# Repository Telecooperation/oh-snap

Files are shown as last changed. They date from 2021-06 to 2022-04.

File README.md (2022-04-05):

<p align="center">
  Oh, Snap!
</p>

<h1 align="center">Oh, Snap!</h1>
<p align="center">A Fabrication Pipeline to Magnetically Connect Conventional and 3D-Printed Electronics.</p>

<div align="center">
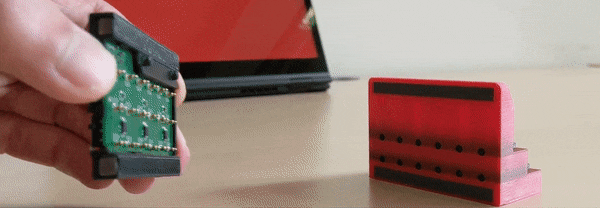
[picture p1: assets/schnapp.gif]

  <br />
    <!--<a href="https://github.com/othneildrew/Best-README-Template"><strong>Explore the docs »</strong></a>
    <br />
    <br />-->
  <h4 align="center">
    <a href="https://www.youtube.com/watch?v=JX3ZwKnnJVs">Watch Teaser</a>
    ·
    <a href="/assets/Schmitz2021-OhSnap.pdf">View PDF</a>
    ·
    <a href="https://www.youtube.com/watch?v=0AUrrtwaPVQ">Watch Talk</a>
    ·
    <a href="https://doi.org/10.1145/3411764.3445641">Follow DOI</a>
    </h4>
</div>

## Paper Abstract
3D printing has revolutionized rapid prototyping by speeding up the creation of custom-shaped objects. With the rise of multi-material 3D printers, these custom-shaped objects can now be made interactive in a single pass through passive conductive structures. However, connecting conventional electronics to these conductive structures often still requires time-consuming manual assembly involving many wires, soldering or gluing.

To alleviate these shortcomings, we propose <i>Oh, Snap!</i>: a fabrication pipeline and interfacing concept to magnetically connect a 3D-printed object equipped with passive sensing structures to conventional sensing electronics. To this end, <i>Oh, Snap!</i> utilizes ferromagnetic and conductive 3D-printed structures, printable in a single pass on standard printers. We further present a proof-of-concept capacitive sensing board that enables easy and robust magnetic assembly to quickly create interactive 3D-printed objects. We evaluate <i>Oh, Snap!</i> by assessing the robustness and quality of the connection and demonstrate its broad applicability by a series of example applications.

## How to use
We provide the schematics and firmware for the Oh, Snap board for capacitive sensing, as well as sample code and 3D models used for the example applications in the paper.

### Schematics
The [schematics](/schematics/) folder contains all schematics to clone the presented Oh, Snap board or use them as a basis for another kind of board. The schematics are provided in Eagle format.

### Firmware
The [firmware](/firmware/) folder contains the firmware required to operate the Oh, Snap board. Please see [firmware/README.md](/firmware/README.md) for more details on the flashing procedure.

### Example Applications
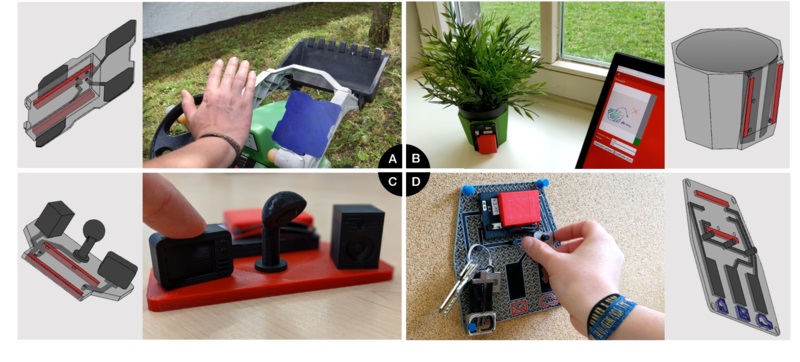
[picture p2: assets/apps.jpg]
Apps


The [examples](/examples/) folder contains code for some example applications:
- [Car Gesture](examples/gesture) (A)
- [Flowerpot](examples/flowerpot) (B)
- [Smarthome Control](examples/smarthome) (C)
- [Piano](examples/piano)

In addition, it also contains some simple monitoring demos.

### 3D Models
For the 3D models used for the example applications and the evaluation see [here](models/).

## How to cite
Please cite this work like this:
<pre>
  Martin Schmitz, Jan Riemann, Florian Müller, Steffen Kreis, and Max Mühlhäuser. 2021. 
  Oh, Snap! A Fabrication Pipeline to Magnetically Connect Conventional and 3D-Printed Electronics. 
  In Proceedings of the 2021 CHI Conference on Human Factors in Computing Systems (CHI ’21), 1–11. 
  https://doi.org/10.1145/3411764.3445641
  </pre>

or use this

<pre>
@inproceedings{10.1145/3411764.3445641,
author = {Schmitz, Martin and Riemann, Jan and M\"{u}ller, Florian and Kreis, Steffen and M\"{u}hlh\"{a}user, Max},
title = {Oh, Snap! A Fabrication Pipeline to Magnetically Connect Conventional and 3D-Printed Electronics},
year = {2021},
isbn = {9781450380966},
publisher = {Association for Computing Machinery},
address = {New York, NY, USA},
url = {https://doi.org/10.1145/3411764.3445641},
doi = {10.1145/3411764.3445641},
booktitle = {Proceedings of the 2021 CHI Conference on Human Factors in Computing Systems},
articleno = {420},
numpages = {11},
keywords = {capacitive sensing, proximity, touch, prototyping, 3D printing},
location = {Yokohama, Japan},
series = {CHI '21}
}
</pre>

## Credits
This project uses the following sources:
- [Protocentral FDC1004](https://github.com/Protocentral/ProtoCentral_fdc1004_breakout)
- [ESPAsyncWebServer](https://github.com/me-no-dev/ESPAsyncWebServer)
- [MQTT PubSubClient](https://github.com/knolleary/pubsubclient)
- [ArduinoJSON]( https://github.com/bblanchon/ArduinoJson)
- [FreeRTOS]( https://github.com/FreeRTOS/FreeRTOS)
- [Tone.js]( https://github.com/Tonejs/Tone.js)
- [Plotly.js](https://github.com/plotly/plotly.js)
- [Arduino-ESP32](https://github.com/espressif/arduino-esp32)
- [Logo](https://www.pngaaa.com/detail/1826967)

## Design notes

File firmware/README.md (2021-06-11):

# Firmware

## Compile & Flash
- Install VSCode and PlatformIO
- Build the firmware and upload it to the (USB connected) devices

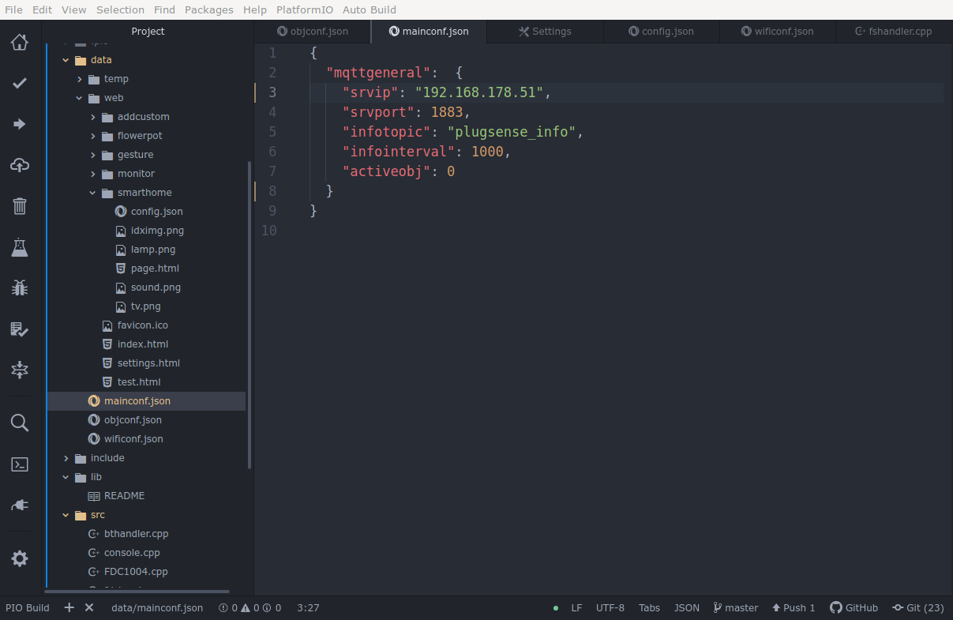
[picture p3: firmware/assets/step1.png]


##  Flash DATA section

- PIO Build (or similar)
- „PIO Upload File System Image“

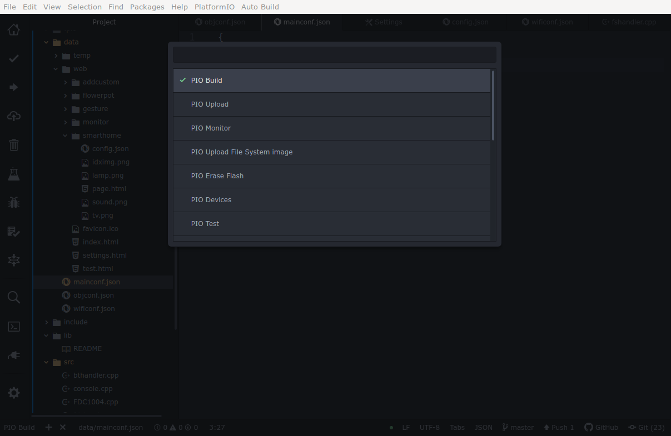
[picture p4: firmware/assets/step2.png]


DATA section contains web and configuration files. This operation builds a DATA object from everything in the „data“ folder and transfers it to the memory.

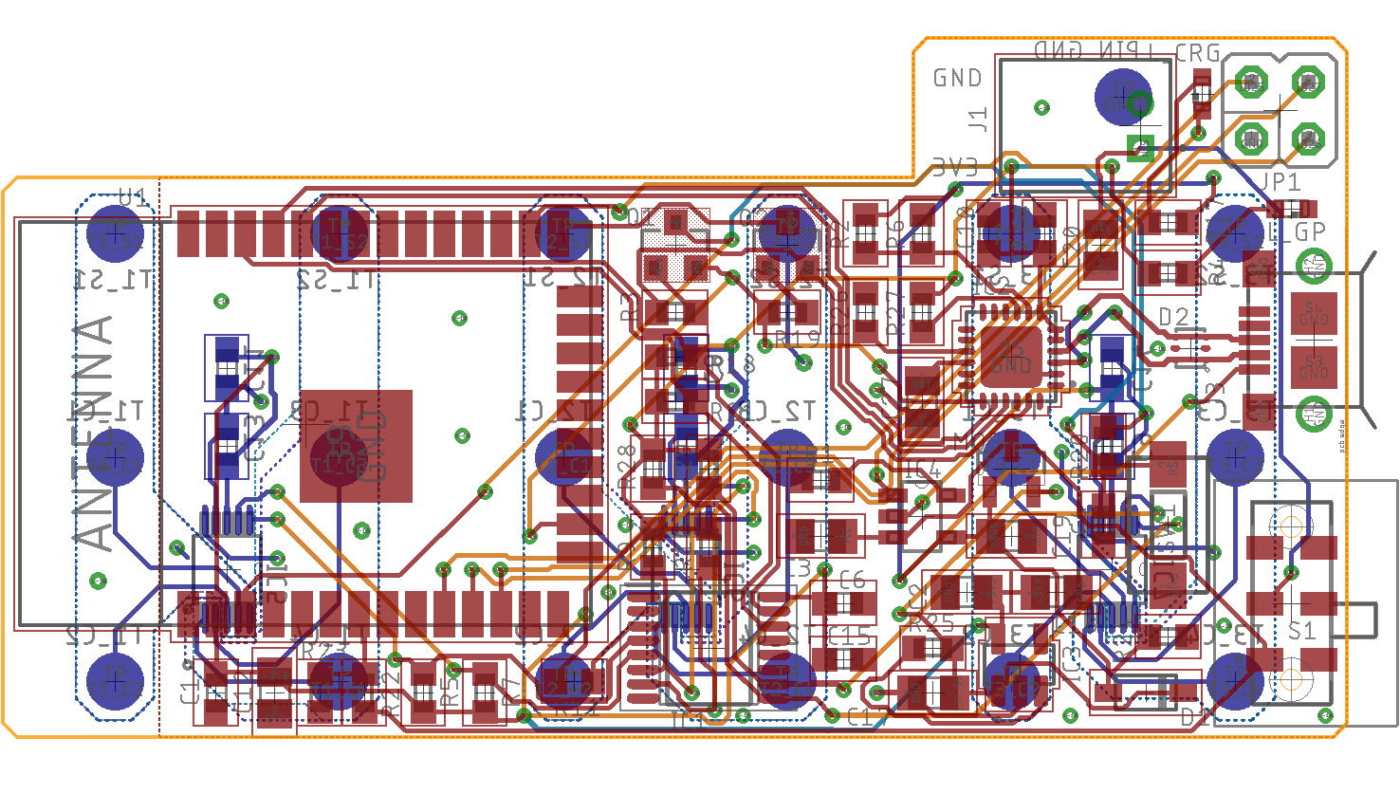
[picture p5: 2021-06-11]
schematics/images/ohsnap_board_extraGND_brd.png

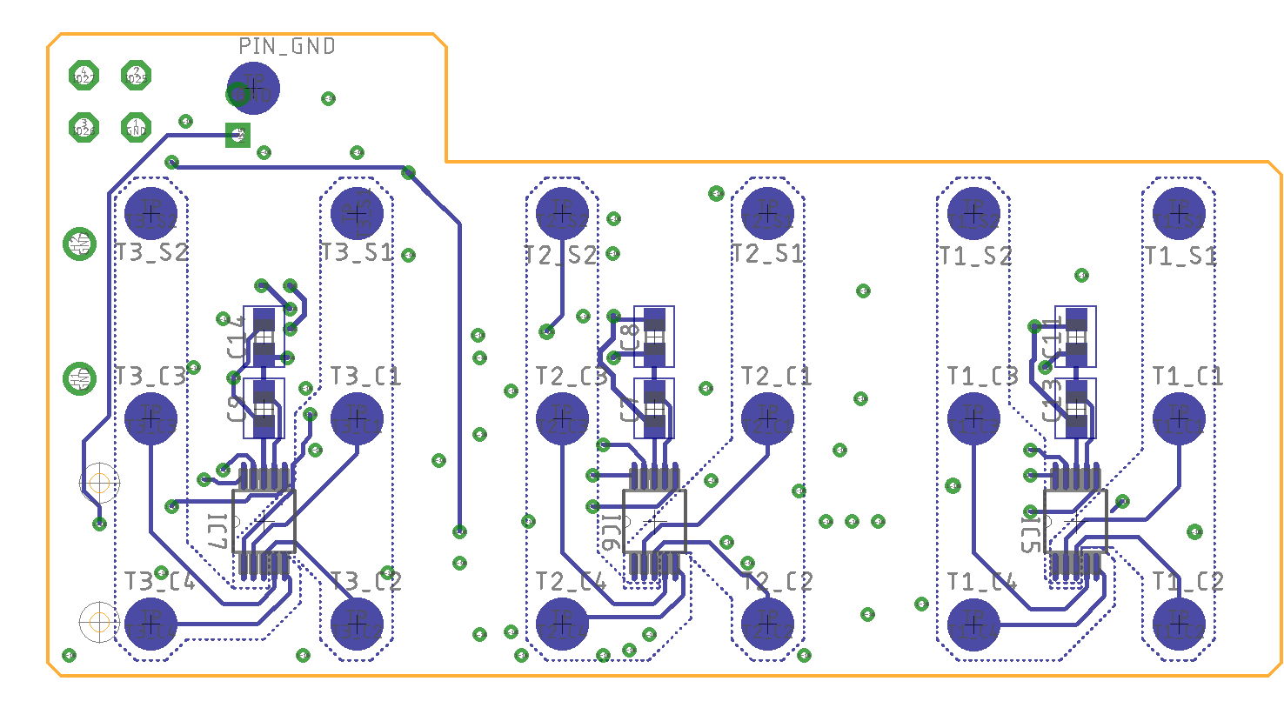
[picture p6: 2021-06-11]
schematics/images/ohsnap_board_extraGND_brd_btm.png

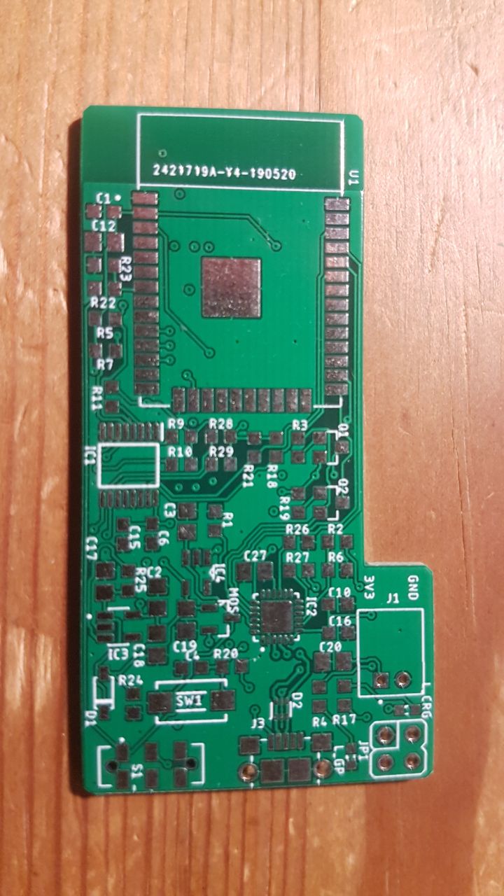
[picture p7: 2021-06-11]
schematics/images/brd_real_top.jpg

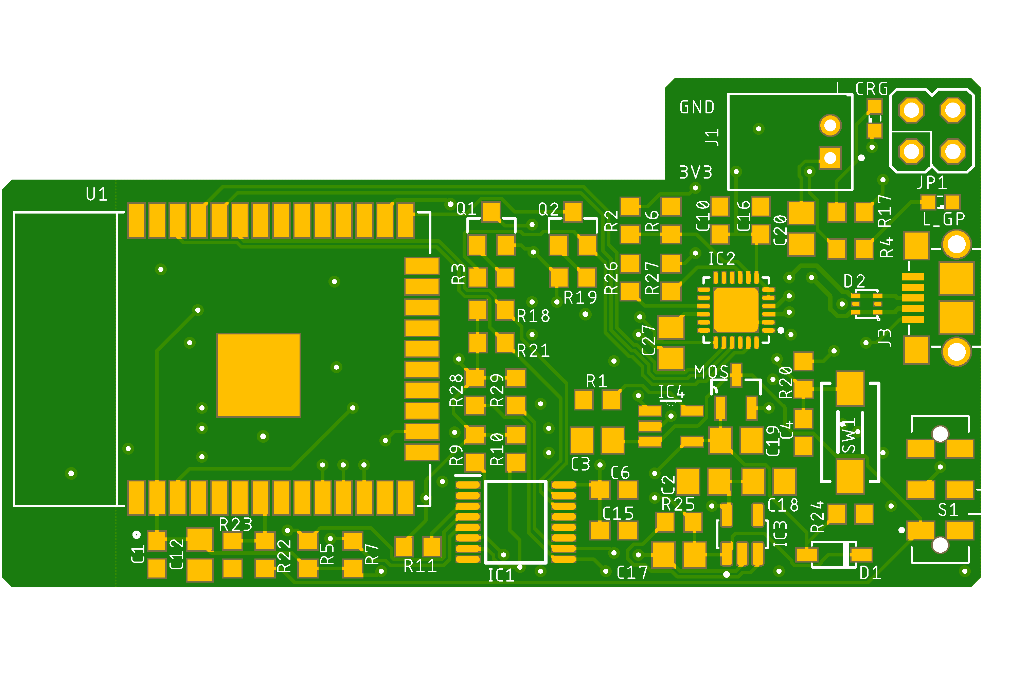
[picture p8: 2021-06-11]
schematics/images/ohsnap_board.png

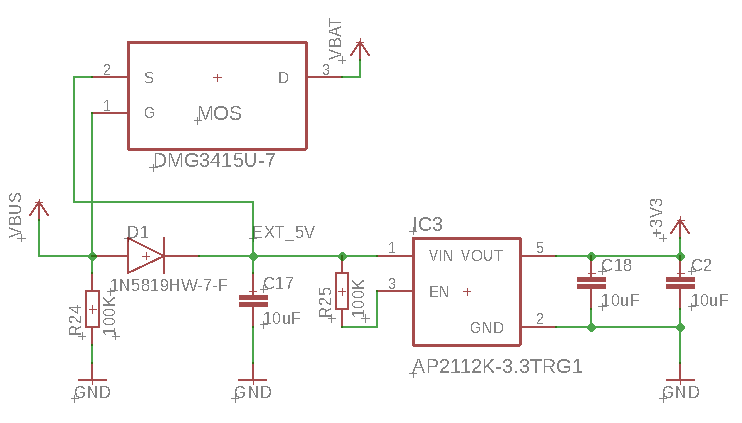
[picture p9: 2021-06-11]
schematics/images/power.png

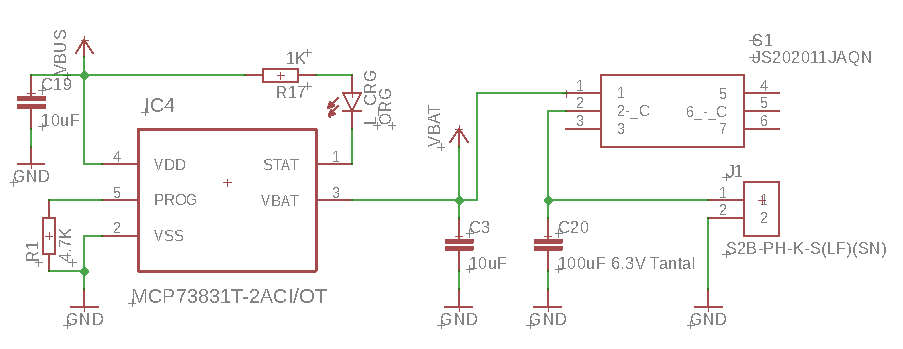
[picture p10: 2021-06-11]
schematics/images/charge.png

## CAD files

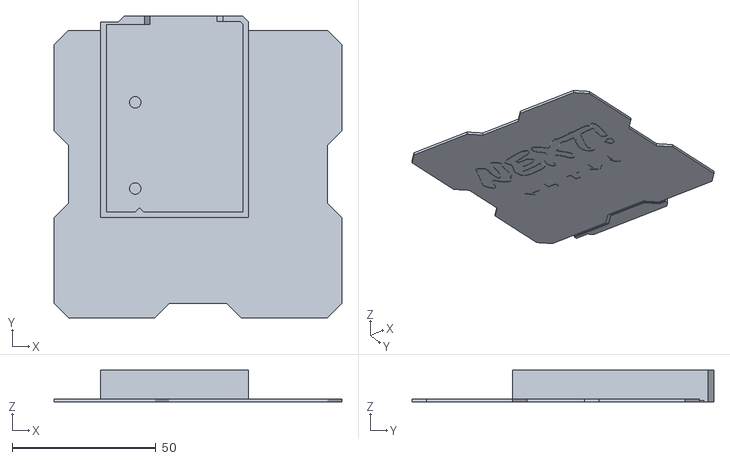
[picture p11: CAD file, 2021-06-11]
models/cargesture/CarGestureControl_bigint_v2.0.stl
100.0 x 105.0 x 11.1

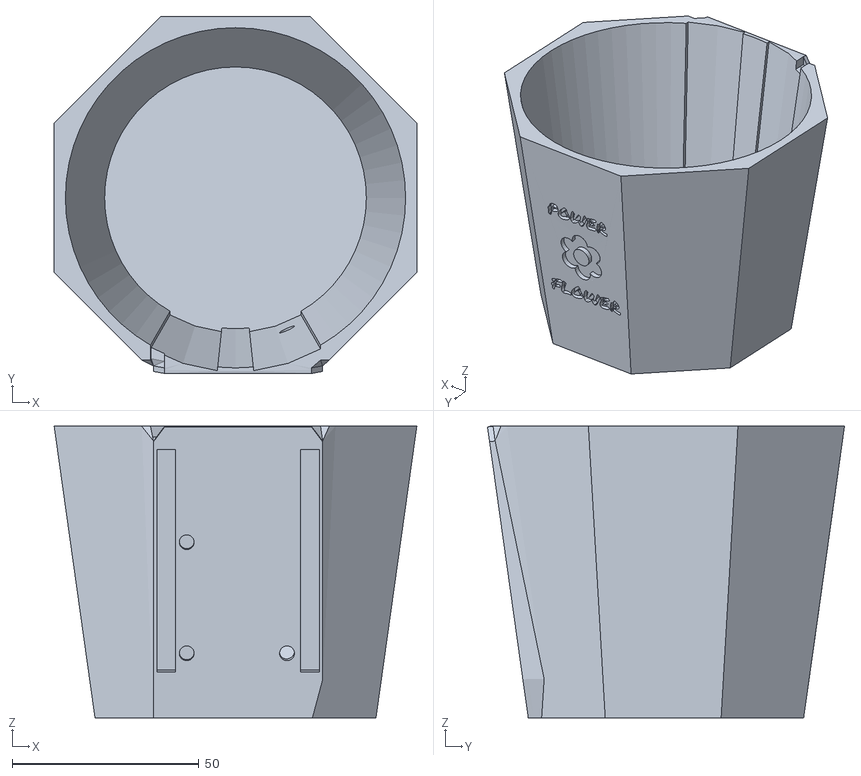
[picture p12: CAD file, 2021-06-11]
models/flowerpot/flowerpot_v5.1_body.stl
97.0 x 95.5 x 78.0

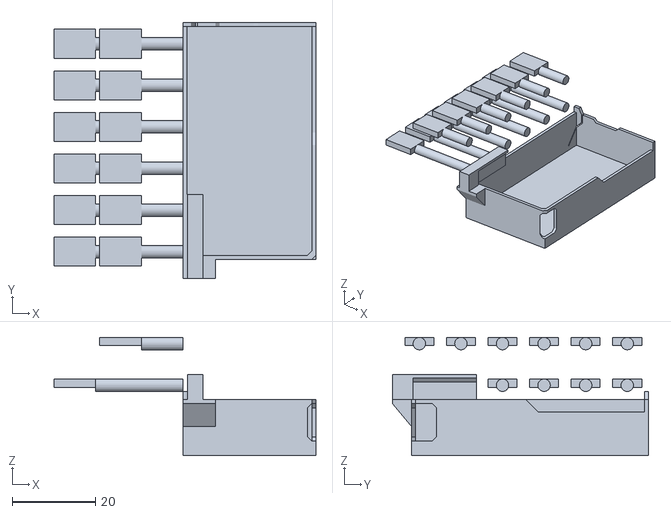
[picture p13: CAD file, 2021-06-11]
models/piano/piano_v5.0_electric.stl
63.0 x 61.6 x 28.4

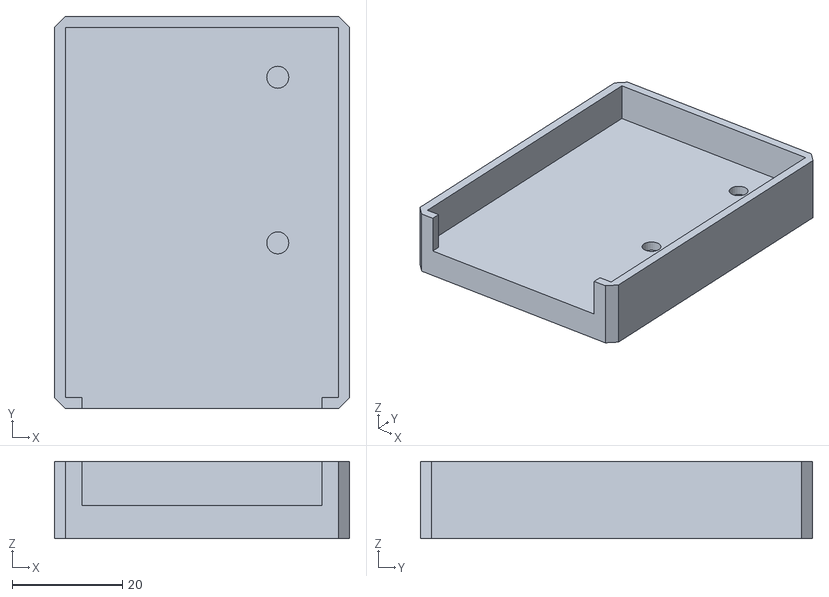
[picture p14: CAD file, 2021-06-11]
models/presenter/presenter_v1.0.stl
53.5 x 71.0 x 14.0

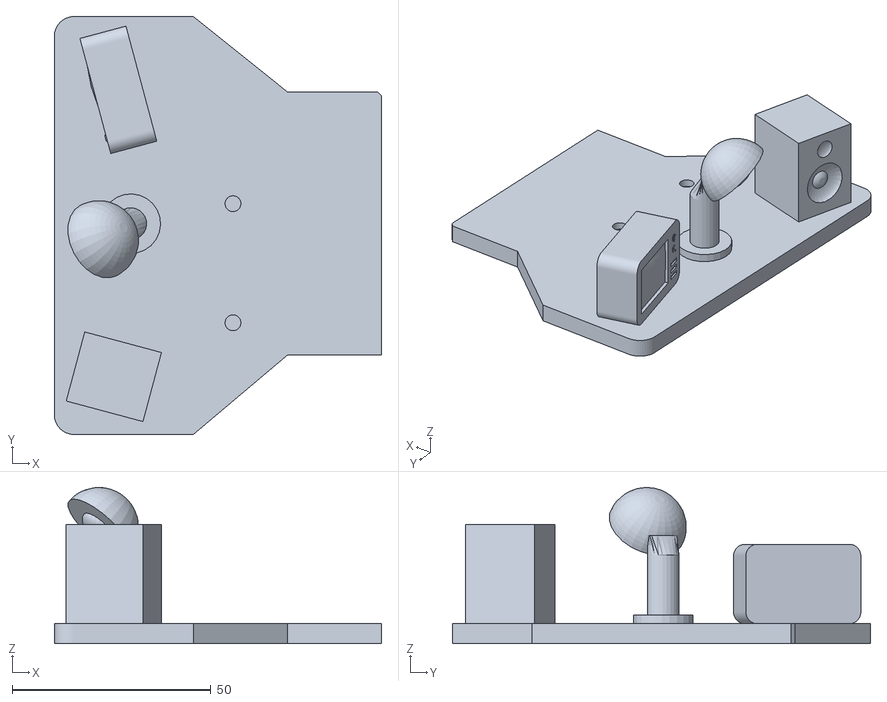
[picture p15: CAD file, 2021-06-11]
models/smarthome/smarthome_v2.1.stl
82.5 x 105.2 x 39.3

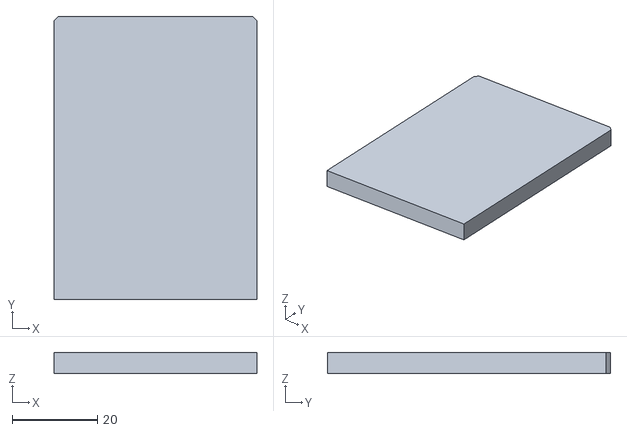
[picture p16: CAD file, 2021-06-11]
models/test interface/ps_interface_v2.1_electric.stl
47.5 x 66.2 x 5.00

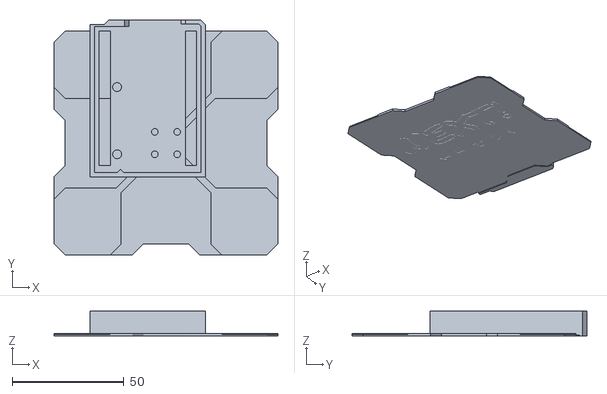
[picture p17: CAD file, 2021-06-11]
models/cargesture/CarGestureControl_bigint_v2.0_body.stl
100.0 x 105.0 x 11.1

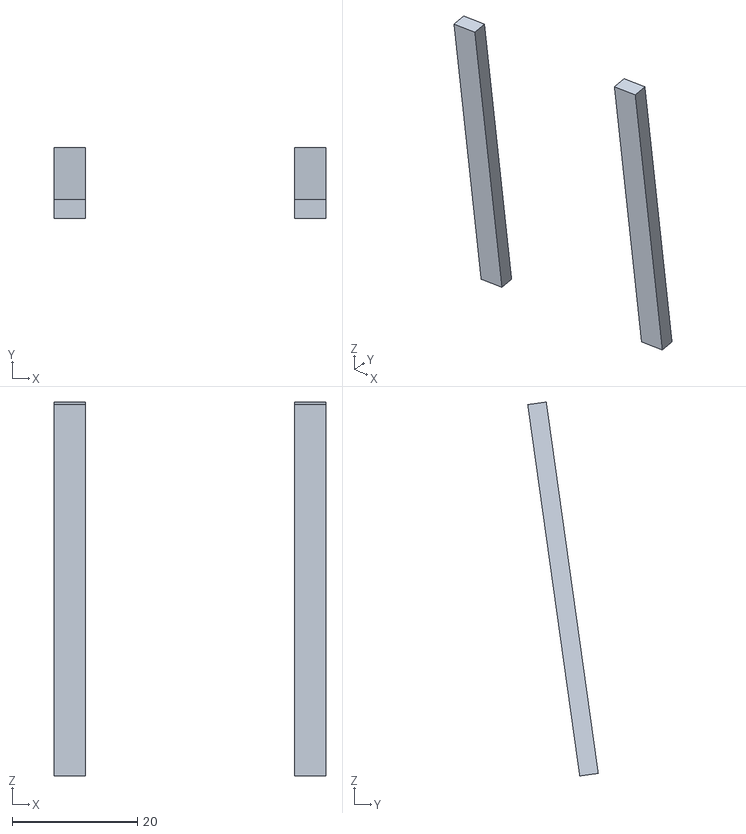
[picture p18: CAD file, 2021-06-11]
models/flowerpot/flowerpot_v5.1_magnetic.stl
43.5 x 11.3 x 59.8

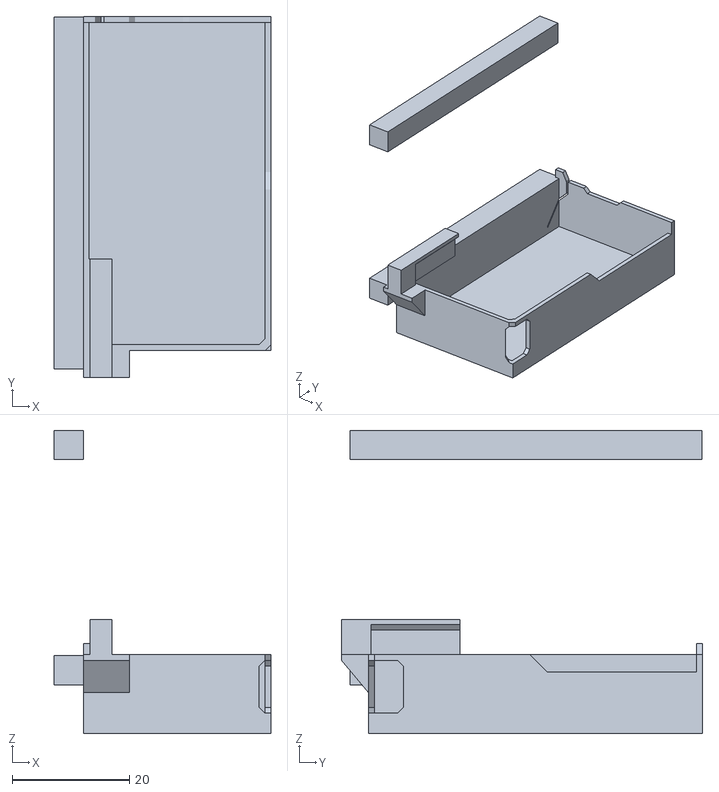
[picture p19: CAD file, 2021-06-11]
models/piano/piano_v5.0_magnetic.stl
37.0 x 61.6 x 51.7

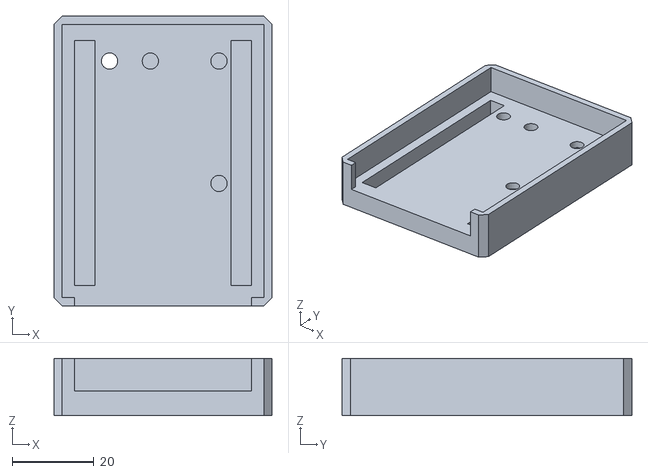
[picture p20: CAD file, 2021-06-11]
models/presenter/presenter_v1.0_body.stl
53.5 x 71.0 x 14.0

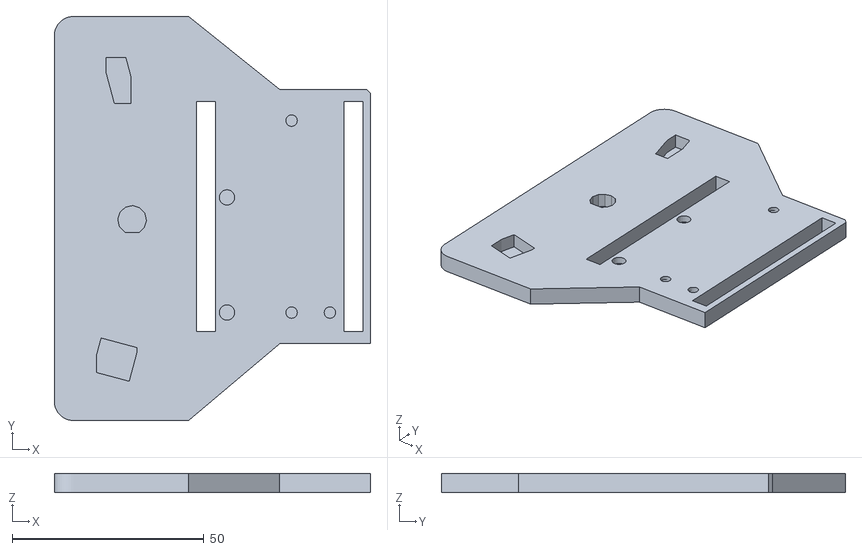
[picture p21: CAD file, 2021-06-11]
models/smarthome/smarthome_v2.1_body.stl
82.5 x 105.2 x 5.00

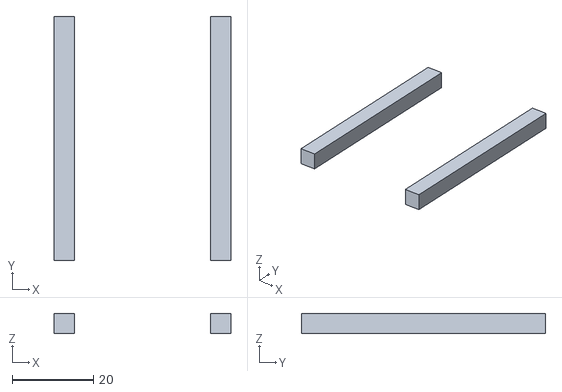
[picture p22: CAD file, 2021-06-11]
models/cargesture/CarGestureControl_bigint_v2.0_magnetic.stl
43.5 x 60.0 x 5.00

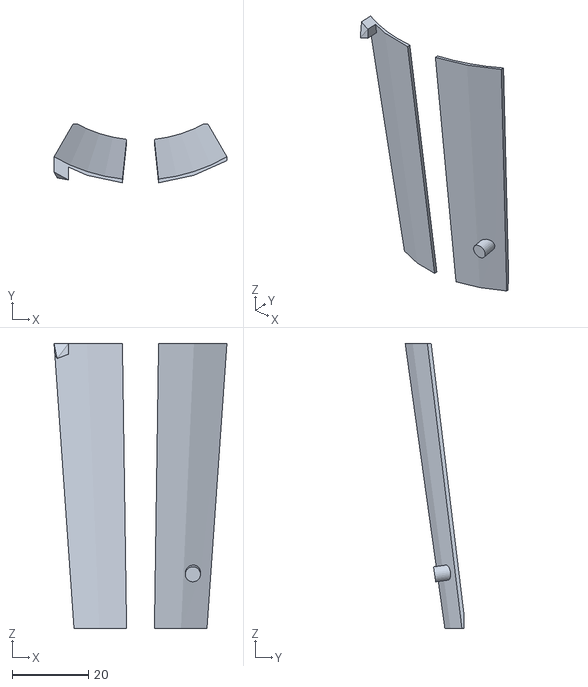
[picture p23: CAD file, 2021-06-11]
models/flowerpot/flowerpot_v5.1_electric.stl
45.5 x 15.4 x 75.0

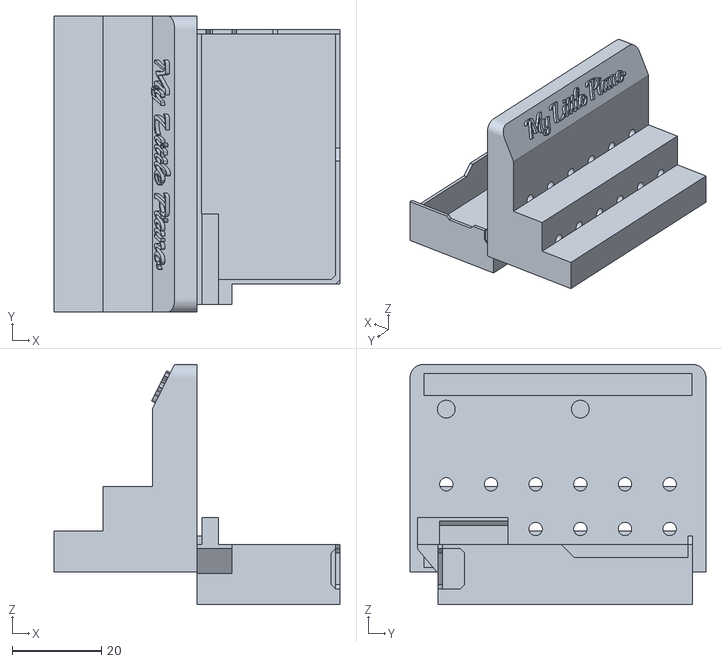
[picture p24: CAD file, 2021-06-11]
models/piano/piano_v5.0_body.stl
64.0 x 66.2 x 53.7

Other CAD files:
models/test interface/ps_interface_v2.1_body.stl
models/presenter/presenter_v1.0_magnetic.stl
models/smarthome/smarthome_v2.1_magnetic.stl
models/test interface/ps_interface_v2.1_magnetic.stl
models/cargesture/CarGestureControl_bigint_v2.0.dwg
models/cargesture/CarGestureControl_bigint_v2.0.dxf
models/cargesture/CarGestureControl_bigint_v2.0.skp
models/cargesture/CarGestureControl_bigint_v2.0_body.dwg
models/cargesture/CarGestureControl_bigint_v2.0_body.dxf
models/cargesture/CarGestureControl_bigint_v2.0_electric.dwg
models/cargesture/CarGestureControl_bigint_v2.0_electric.dxf
models/cargesture/CarGestureControl_bigint_v2.0_electric.stl
models/cargesture/CarGestureControl_bigint_v2.0_magnetic.dwg
models/cargesture/CarGestureControl_bigint_v2.0_magnetic.dxf
models/flowerpot/flowerpot_v5.1.dwg
models/flowerpot/flowerpot_v5.1.dxf
models/flowerpot/flowerpot_v5.1.skp
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

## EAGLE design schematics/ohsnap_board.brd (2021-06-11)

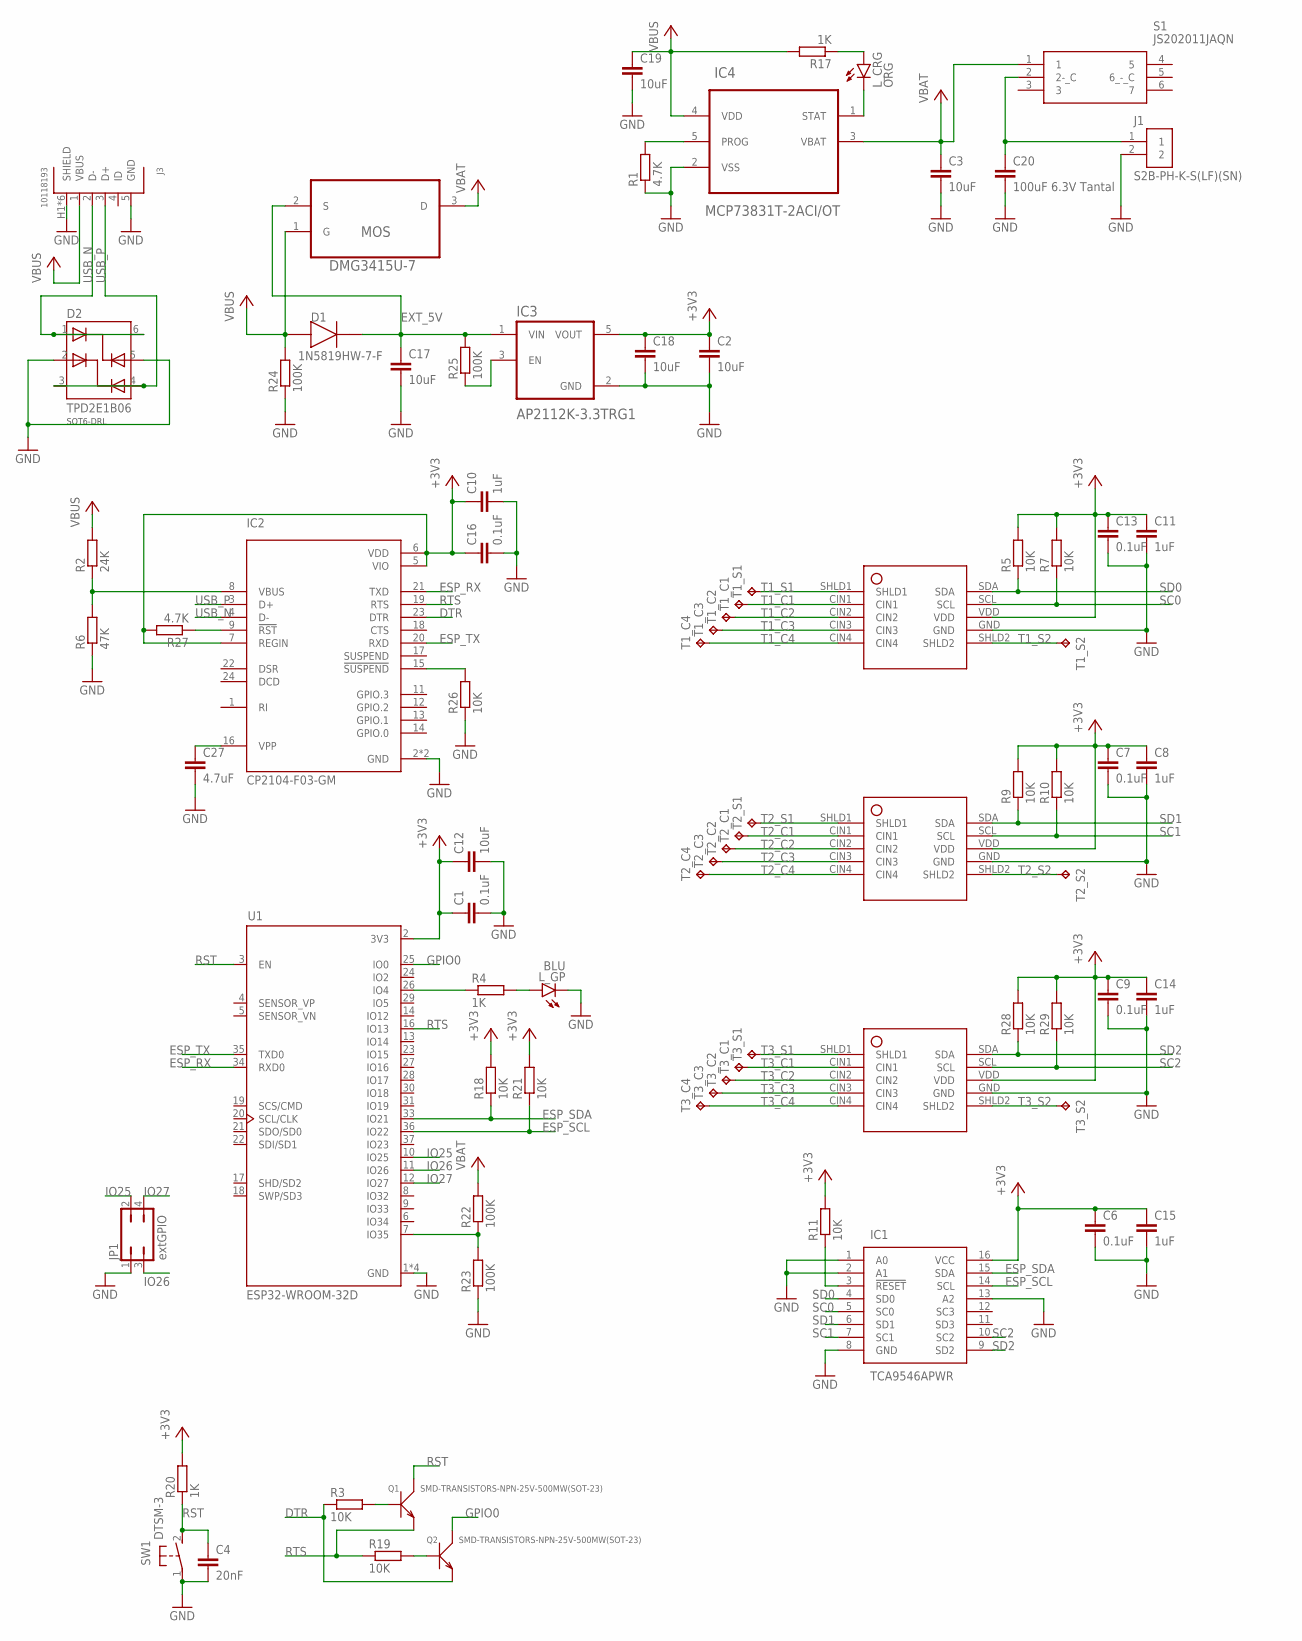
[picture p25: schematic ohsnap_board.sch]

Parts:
C1, C6, C7, C9, C13, C16: 0.1uF; C0603
C2, C3, C12, C17, C18, C19: 10uF; C0805
C4: 20nF; C0603
C8, C10, C11, C14, C15: 1uF; C0603
C20: 100uF 6.3V Tantal; C0805
C27: 4.7uF; C0805
D1: 1N5819HW-7-F; SOD370155X135
D2: TPD2E1B06; SOT6-DRL
IC1: TCA9546APWR; SOP65P640X120-16N
IC2: CP2104-F03-GM; QFN50P400X400X80-25N
IC3: AP2112K-3.3TRG1; SOT95P285X140-5N
IC4: MCP73831T-2ACI/OT; SOT95P280X145-5N
IC5, IC6, IC7: FDC1004_SOP10; SOP50P490X109-10N
J1: S2B-PH-K-S(LF)(SN); JST_S2B-PH-K-S(LF)(SN)
J3: 10118193
JP1: extGPIO; JP2Q
L_CRG: ORG; SML0603
L_GP: BLU; SML0603
MOS: DMG3415U-7; SOT95P240X105-3N
Q1, Q2: SMD-TRANSISTORS-NPN-25V-500MW(SOT-23); SOT-23
R1, R27: 4.7K; R0603
R2: 24K; R0603
R3, R5, R7, R9, R10, R11, R18, R19, R21, R26, R28, R29: 10K; R0603
R4, R17, R20: 1K; R0603
R6: 47K; R0603
R22, R23, R24, R25: 100K; R0603
S1: JS202011JAQN
SW1: DTSM-3
T1_C1, T1_C2, T1_C3, T1_C4, T2_C1, T2_C2, T2_C3, T2_C4, T3_C1, T3_C2, T3_C3, T3_C4: TPB2,54; B2,54
T1_S1: T1_S1; B2,54
T1_S2: T1_SHLD2; B2,54
T2_S1: T2_SHLD1; B2,54
T2_S2: T2_SHLD2; B2,54
T3_S1: T3_SHLD1; B2,54
T3_S2: T3_S2; B2,54
U1: ESP32-WROOM-32D; MODULE_ESP32-WROOM-32D

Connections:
+3V3: C1.1, C2.1, C6.1, C7.1, C8.1, C9.1, C10.1, C11.1, C12.1, C13.1, C14.1, C15.1, C16.1, C18.1, IC1.16 (VCC), IC2.5 (VIO), IC2.6 (VDD), IC2.7 (REGIN), IC3.5 (VOUT), IC5.VDD, IC6.VDD, IC7.VDD, R5.2, R7.2, R9.2, R10.2, R11.2, R18.2, R20.2, R21.2, R27.2, R28.2, R29.2, U1.2 (3V3)
DTR: IC2.23 (DTR), Q2.2 (E), R3.1
ESP_RX: IC2.21 (TXD), U1.34 (RXD0)
ESP_SCL: IC1.14 (SCL), R21.1, U1.36 (IO22)
ESP_SDA: IC1.15 (SDA), R18.1, U1.33 (IO21)
ESP_TX: IC2.20 (RXD), U1.35 (TXD0)
EXT_5V: C17.1, D1.1 (C), IC3.1 (VIN), MOS.2 (S), R25.2
GND: C1.2, C2.2, C3.2, C4.2, C6.2, C7.2, C8.2, C9.2, C10.2, C11.2, C12.2, C13.2, C14.2, C15.2, C16.2, C17.2, C18.2, C19.2, C20.2, C27.2, D2.2 (IOB1), D2.5 (IOA2), IC1.1 (A0), IC1.2 (A1), IC1.8 (GND), IC1.13 (A2), IC2.2 (GND), IC2.25 (GND), IC3.2 (GND), IC4.2 (VSS), IC5.GND, IC6.GND, IC7.GND, J1.2, J3.5 (GND), J3.H1 (SHIELD), J3.H2 (SHIELD), J3.S1 (SHIELD), J3.S2 (SHIELD), J3.S3 (SHIELD), J3.S4 (SHIELD), JP1.1, L_GP.C, R1.1, R6.1, R23.1, R24.1, R26.1, SW1.1, U1.1 (GND), U1.15 (GND), U1.38 (GND), U1.39 (GND)
GPIO0: Q2.3 (C), U1.25 (IO0)
IO25: JP1.2, U1.10 (IO25)
IO26: JP1.3, U1.11 (IO26)
IO27: JP1.4, U1.12 (IO27)
unnamed: L_GP.A, R4.2
unnamed: R4.1, U1.26 (IO4)
unnamed: IC3.3 (EN), R25.1
unnamed: R22.1, R23.2, U1.7 (IO35)
unnamed: C20.1, J1.1, S1.2 (2-_C)
unnamed: IC2.15 (!SUSPEND), R26.2
unnamed: C27.1, IC2.16 (VPP)
unnamed: IC2.8 (VBUS), R2.1, R6.2
unnamed: IC2.9 (!RST), R27.1
unnamed: Q1.1 (B), R3.2
unnamed: Q2.1 (B), R19.2
unnamed: IC1.3 (!RESET), R11.1
unnamed: IC4.1 (STAT), L_CRG.C
unnamed: L_CRG.A, R17.1
unnamed: IC4.5 (PROG), R1.2
RST: C4.1, Q1.3 (C), R20.1, SW1.2, U1.3 (EN)
RTS: IC2.19 (RTS), Q1.2 (E), R19.1, U1.16 (IO13)
SC0: IC1.5 (SC0), IC5.SCL, R7.1
SC1: IC1.7 (SC1), IC6.SCL, R10.1
SC2: IC1.10 (SC2), IC7.SCL, R29.1
SD0: IC1.4 (SD0), IC5.SDA, R5.1
SD1: IC1.6 (SD1), IC6.SDA, R9.1
SD2: IC1.9 (SD2), IC7.SDA, R28.1
T1_C1: IC5.CIN1, T1_C1.TP
T1_C2: IC5.CIN2, T1_C2.TP
T1_C3: IC5.CIN3, T1_C3.TP
T1_C4: IC5.CIN4, T1_C4.TP
T1_S1: IC5.SHLD1, T1_S1.TP
T1_S2: IC5.SHLD2, T1_S2.TP
T2_C1: IC6.CIN1, T2_C1.TP
T2_C2: IC6.CIN2, T2_C2.TP
T2_C3: IC6.CIN3, T2_C3.TP
T2_C4: IC6.CIN4, T2_C4.TP
T2_S1: IC6.SHLD1, T2_S1.TP
T2_S2: IC6.SHLD2, T2_S2.TP
T3_C1: IC7.CIN1, T3_C1.TP
T3_C2: IC7.CIN2, T3_C2.TP
T3_C3: IC7.CIN3, T3_C3.TP
T3_C4: IC7.CIN4, T3_C4.TP
T3_S1: IC7.SHLD1, T3_S1.TP
T3_S2: IC7.SHLD2, T3_S2.TP
USB_N: D2.1 (IOA1), D2.6 (NC), IC2.4 (D-), J3.2 (D-)
USB_P: D2.3 (NC), D2.4 (IOB2), IC2.3 (D+), J3.3 (D+)
VBUS: C19.1, D1.2 (A), IC4.4 (VDD), J3.1 (VBUS), MOS.1 (G), R2.2, R17.2, R24.2
VCC: C3.1, IC4.3 (VBAT), MOS.3 (D), R22.2, S1.1

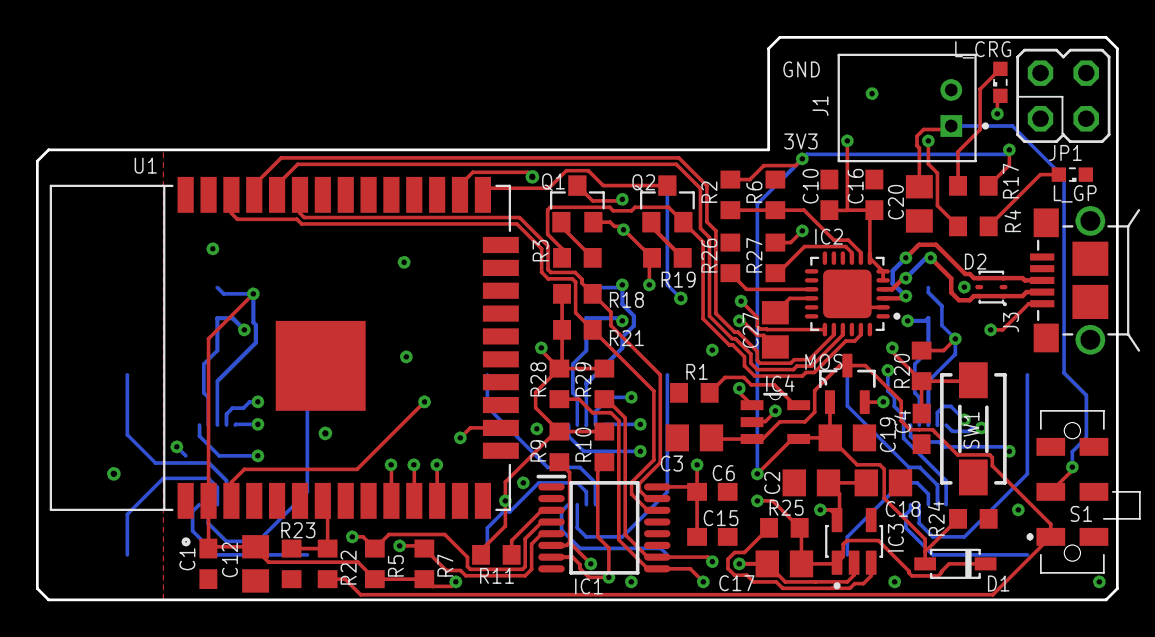
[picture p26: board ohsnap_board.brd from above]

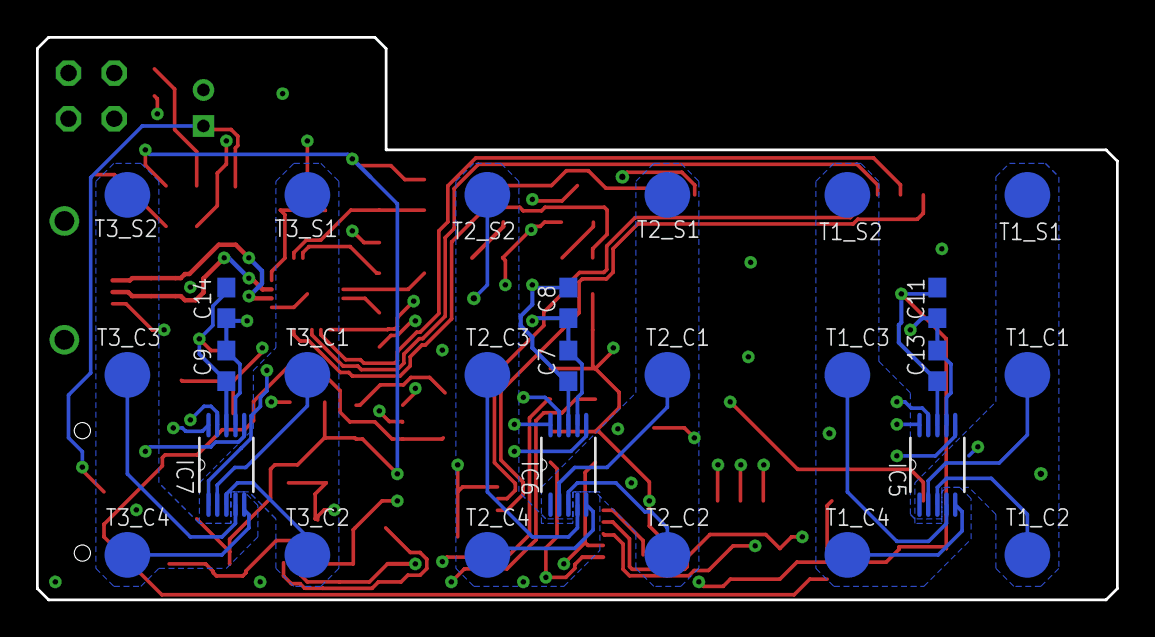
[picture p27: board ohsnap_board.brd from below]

Board: 4 copper layers, 60.0 x 31.2 mm, 81 parts (27 on the bottom side), 57 nets.

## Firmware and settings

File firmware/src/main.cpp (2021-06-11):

#include <stdio.h>
#include <esp_system.h>
#include <FreeRTOS.h>
#include "fshandler.h"
#include "wifihandler.h"
#include "console.h"
#include "mqtthandler.h"
#include "utilities.h"
#include "defines.h"
// bt handling // currently disabled due to high progmem use
//#include "bthandler.h"
#include "website.h"
#include "fdctouch.h"

bool wifi_connected = false;

mqttconfstruct mqttconf;
mqttobjs objs;

void setup() {
  Serial.begin(115200);

  setup_led();
  //setup_bluetooth();

  if(setup_filesys()){

    mqttobjs objs;
    listDir(SPIFFS, "/", objs, false);
    mqttconf = read_mqtt_json(mqttconf);
    mqttconf.objs = objs;
    for(mqttobjstruct obj : objs){
      read_objconf_json(obj);
    }

    setup_battery_check();

    wifi_connected = wifi_connect();

    xTaskCreate(toucheck_task, "toucheck_task", 4096, NULL, 4, NULL);
    xTaskCreate(console_task, "console_task", 4096, NULL, 5, NULL);

    if(!wifi_connected){
      Serial.println("No Wi-Fi connection available, MQTT and web services won't work.");
    }else{
      setup_website(objs);
      //xTaskCreate(website_task, "website_task", 2048, NULL, 5, NULL);
      register_web_callback(web_callback_array);
      register_mqtt_callback(mqtt_callback_array);

      setup_mqtt(mqttconf, objs);
    }
    delay(100); // console cb reg had problems with immediate call
    register_console_callback(console_callback_array);

  /*
    ledcAttachPin(25, 2);    //Configure variable led, pin 18 to channel 1
    ledcSetup(2, 12000, 8);   // 12 kHz PWM and 8 bit resolution
    ledcWrite(2, 255);        // Write a test value of 100 to channel 1
  */
  }
}


void loop(){
  // tasks outsourced to FreeRTOS tasks
  //Serial.println(get_battery_level());


}

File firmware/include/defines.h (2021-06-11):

#pragma once

//mqtt keywords
#define MQTT_THRESH "<threshold>"
#define MQTT_VALUE "<value>"
#define MQTT_SENSOR "<sensor>"

//sensors
#define TCAADDR 0x70 // for v1.0 try 0x70-0x73

#define FDC_CHIPS 3													//how many FDC1004 chips are on the sensor board
#define INPUTS_PER_FDC 4										//how many inputs are used per FDC1004 chip
#define DISMISS_FIRST_N_MEASUREMENTS 50			//how many values to dismiss to give sensor time to calibrate
#define MEASUREMENT_FREQUENCY FDC1004_100HZ //the frequency of a single reading. slower means higher precision. can be 100HZ, 200HZ, 400HZ.

#define SENSOR_COUNT FDC_CHIPS*INPUTS_PER_FDC

//battery
#define VOLTAGE_CONV_FACTOR 2*3.45*1000/4096

//wifi
#define WIFI_CONNECT_KEYWORD "wificonnect"

#define LED_PIN 4
#define LED_CHANNEL 1

#define FS_MAX_LENGTH 32


#define CONSOLE_VAL_INTERVAL 100
